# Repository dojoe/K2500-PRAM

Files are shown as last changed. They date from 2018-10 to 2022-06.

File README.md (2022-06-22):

# K2500 P/RAM
A P/RAM extension remake for Kurzweil K2500 synthesizers

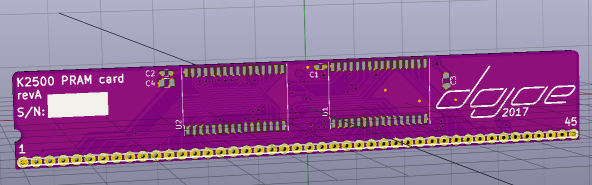
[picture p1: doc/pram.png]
PCB rendering


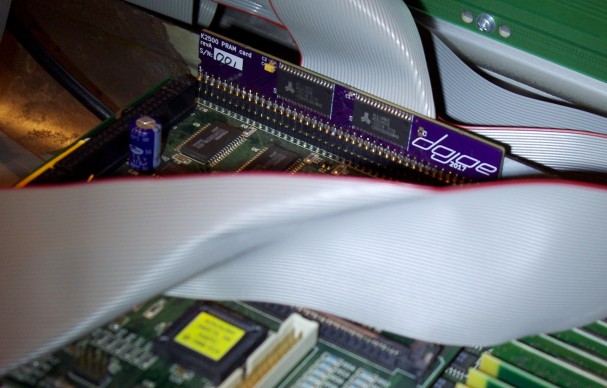
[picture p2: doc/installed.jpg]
Board installed in a K2500


## Why?

Because people are demanding upwards of 100<span>$</span> on eBay for a part that is simple to make and costs about 20<span>$</span>.

## How?

It's basically just a 1MB SRAM board in a 512Kx16 configuration. The original board had eight 128Kx8 SRAMs and some address decoders, 
but thanks to modern technology we don't need that level of complexity as we can just tack two 512Kx8 SRAMs together.
With that, the only tricky part is to get all those wires routed while keeping a low card profile, which is what I did.

## Compatibility

We tested this in a K2500 and it works like a charm. It also works if you have a KDFX installed, it'll fit nicely next to the KDFX board and won't clash with it.

This will _only_ work in a K2500. It is __not compatible__ with the K2000 or the K2600, these both need completely different boards.

And of course I will assume no responsibility for any problems or damage that may arise from you making your own P/RAM from this design and trying it in a synth. Duh ;)

## The board

This repository contains the KiCAD schematics and board file for the P/RAM extension. There's also a zip file with Gerbers
so you can jump right to ordering a board for yourself, or you simply order from OSHPark directly:



## Parts

The board is built around the AS6C4008, a 5V SRAM chip from Alliance Memory. There may be other pin and voltage compatible parts
out there, but the AS6C4008 is cheap and works. Here's the full BOM, almost too boring to print:

| Designator | Description | Digikey part# | Mouser part# |
|---|---|---|---|
| U1, U2 | Alliance Memory AS6C4008-55ZIN | 1450-1031-ND | 913-AS6C4008-55ZIN |
| J1 | Precision pin header, 45pos, 0.1" | e.g. 1212-1176-ND  | e.g. 437-8008006410001101 |
| C1, C2 | Ceramic Cap X7R 0603 100nF | ehh | whatevs |
| C3, C4 | Ceramic Cap X7R 0805 1uF | go find it | anything goes |

The trickiest part is probably J1 - you need a pin header with __round pins__, not the usual square ones.
Unfortunately these guys are expensive, but not prohibitively so.

## Assembly and installation

Solder everything up, pin header last. You need to mount the header so that the pins are in the same plane as the board, so you either need right-angle headers, or you mount the pin header flat onto the pads for an SMD-like connection. In the end the PRAM board should stand upright on the K2500 mainboard:

Board installed in a K2500

Install the card such that pin 1 (numbered and marked by a notch in the card) points towards the closest edge of the mainboard and the memory chips are facing the memory chips on the mainboard -- see the picture above.

The socket inside the K2500 has very tight tolerances, and the pins tend to move during soldering,
so in the end we had to push on the PRAM card really hard for it to properly sit in the socket.
If you can afford taking the processor board out of the K2500, I recommend plugging the pin header into the socket first,
and then soldering the PRAM board to the pin header while it's in the socket. That will keep the pins aligned during
soldering.

Note that the suggested part number for J1 (1212-1176-ND) has pins that are different thicknesses on either end, and the K2500's
PRAM socket is very tight. The pin header has to be soldered on "upside down" - i.e.: with the longer, thicker sides of the pins
soldered to the PRAM board, and the shorter, thinner sides of the pins used to insert into the socket.

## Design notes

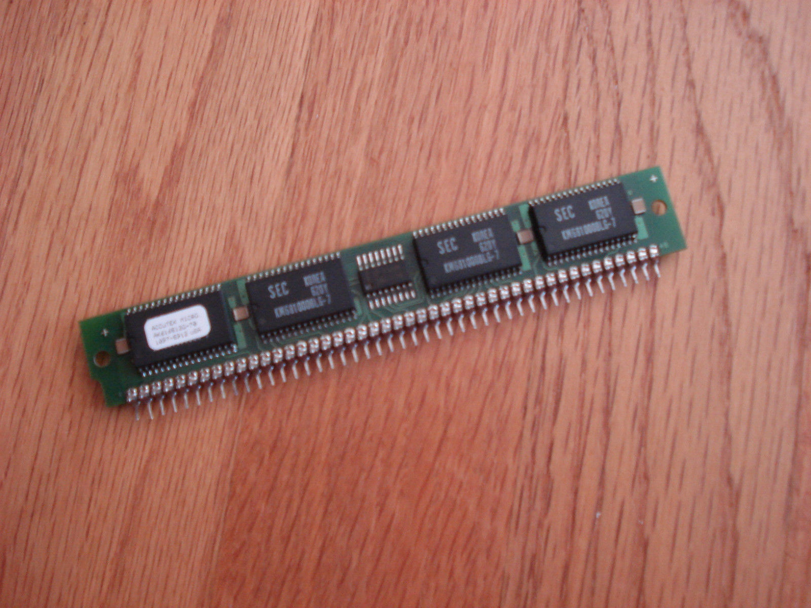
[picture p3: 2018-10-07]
references/s-l1600.jpg

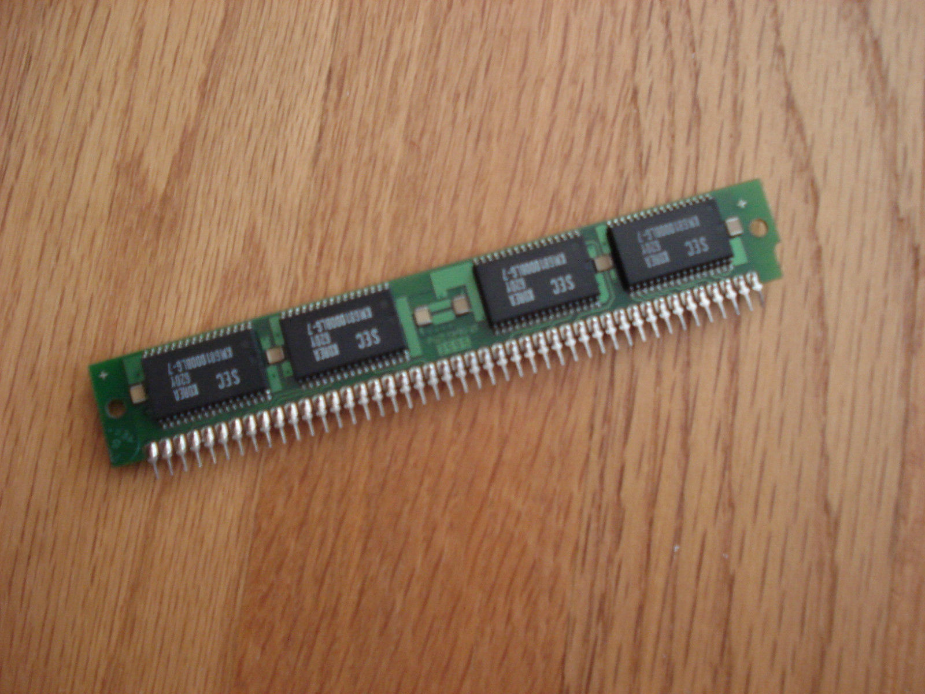
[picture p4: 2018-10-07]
references/s-l1600_2.jpg

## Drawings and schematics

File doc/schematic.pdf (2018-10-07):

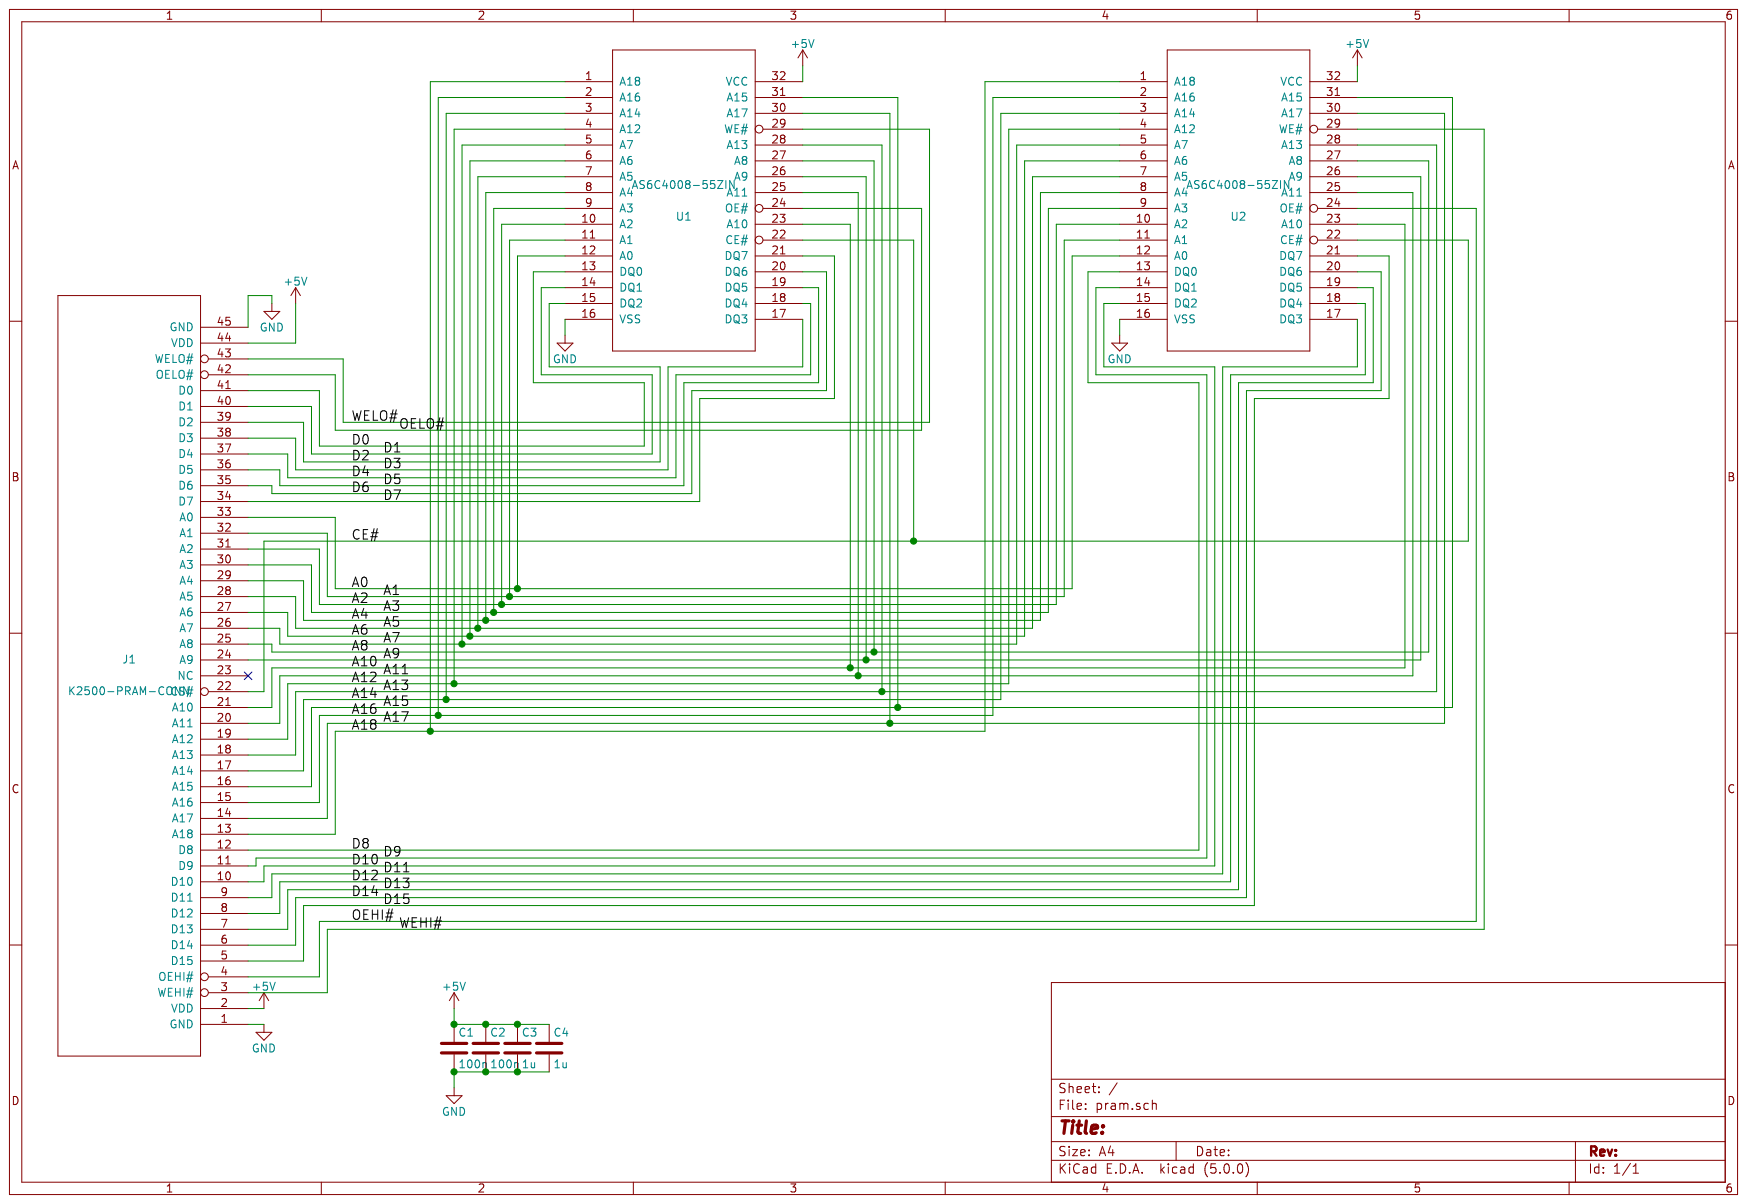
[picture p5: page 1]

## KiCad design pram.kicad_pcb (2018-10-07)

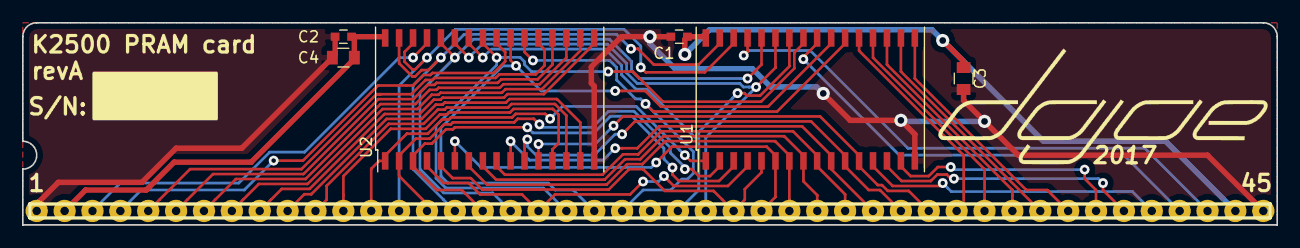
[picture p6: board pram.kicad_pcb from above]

Board: 4 copper layers, 114.3 x 18.4 mm, 8 parts (0 on the bottom side), 42 nets.

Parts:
C1, C2: 100n; C_0603
C3, C4: 1u; C_0805
J1: K2500-PRAM-CONN; PRAMCONN
U1, U2: AS6C4008-55ZIN; TSOP-II-32_21.0x10.2mm_Pitch1.27mm
VAL: REF; dojoe

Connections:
+5V: C1.1, C2.1, C3.1, C4.1, J1.2, J1.44, U1.32, U2.32
/A0: J1.33, U1.12, U2.12
/A1: J1.32, U1.11, U2.11
/A2: J1.31, U1.10, U2.10
/A3: J1.30, U1.9, U2.9
/A4: J1.29, U1.8, U2.8
/A5: J1.28, U1.7, U2.7
/A6: J1.27, U1.6, U2.6
/A7: J1.26, U1.5, U2.5
/A8: J1.25, U1.27, U2.27
/A9: J1.24, U1.26, U2.26
/A10: J1.21, U1.23, U2.23
/A11: J1.20, U1.25, U2.25
/A12: J1.19, U1.4, U2.4
/A13: J1.18, U1.28, U2.28
/A14: J1.17, U1.3, U2.3
/A15: J1.16, U1.31, U2.31
/A16: J1.15, U1.2, U2.2
/A17: J1.14, U1.30, U2.30
/A18: J1.13, U1.1, U2.1
/CE#: J1.22, U1.22, U2.22
/D0: J1.41, U1.13
/D1: J1.40, U1.14
/D2: J1.39, U1.15
/D3: J1.38, U1.17
/D4: J1.37, U1.18
/D5: J1.36, U1.19
/D6: J1.35, U1.20
/D7: J1.34, U1.21
/D8: J1.12, U2.13
/D9: J1.11, U2.14
/D10: J1.10, U2.15
/D11: J1.9, U2.17
/D12: J1.8, U2.18
/D13: J1.7, U2.19
/D14: J1.6, U2.20
/D15: J1.5, U2.21
/OEHI#: J1.4, U2.24
/OELO#: J1.42, U1.24
/WEHI#: J1.3, U2.29
/WELO#: J1.43, U1.29
GND: C1.2, C2.2, C3.2, C4.2, J1.1, J1.45, U1.16, U2.16

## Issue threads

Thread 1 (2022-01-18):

Recommended J1 pin header has pins too thick for some K2500RS models

psobot, 2022-01-18:
Hi @dojoe! This project is great, and I had the pleasure of ordering boards and soldering one of these together recently. Unfortunately, after assembly, I found that the resulting PRAM board didn't fit in my K2500RS - and the pins used on the recommended part for J1 (Precision pin header, 45pos, 0.1" | e.g. 1212-1176-ND) were too thick for the connector on my K2500RS' engine board. (Even a single pin from the header wouldn't fit in the connector slot, when tried independently of the PRAM card; no amount of pushing on caused the pins to fit.)

It might be worth changing the BOM to recommend a header with slightly thinner pins, if one exists.

dojoe, 2022-01-19:
Hi Peter! That's weird, I've built about six of these with the Preci-Dip parts and they all worked fine.

According to the datasheet the two sides have different pin diameters - 0.76mm at the mating side and 0.6mm at the solder side.  I always soldered the thicker side to the board and had the slimmer side sticking out - wasn't even aware I was soldering them the "wrong" way around. Maybe that's what makes the difference between fitting and not fitting.
Apart from this pin shape the only other shape I can find on Digikey is 0.47mm pin thickness; that sounds like it would simply fall out of the socket.

If flipping the header doesn't work for you, maybe one of the 0.47mm parts would work - ED3864-64-ND is one I just found that's got a 0.6mm and a 0.47mm side. Please let me know what you find out so I can update the README, and/or send a PR my way :)

dojoe, 2022-06-22:
Thanks a lot for the follow-up and the PR! ❤️

Closed 2022-06-22.

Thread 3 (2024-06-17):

Right angle header

stobiepole, 2024-06-17:
Hi. I've ordered a PRAM board from OSH Park now I'm looking into headers...would a right angle version like this one - 437-3991016410009101 - from Mouser be suitable?  Seems easier to solder neatly. Thanks, Chris.

sagamusix, 2024-06-17:
I have my doubts that it would have enough clearance above the board that the PRAM is plugged into. If you have your K2500 open, you could check how much clearance is needed.

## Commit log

2018-10-07 Full release
    [pram.kicad_pcb, pram.sch]
2019-05-08 Fix Digikey part number for pin headers
    I accidentally put the part number for 2mm pitch headers here.
    Fixed now. The Mouser part number has been correct from the start.
